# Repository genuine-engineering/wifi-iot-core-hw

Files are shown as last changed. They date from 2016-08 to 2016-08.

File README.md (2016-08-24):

# WIFI-IOT-CORE for IoT production project

_Wifi IoT Core_ project is to combine STM32 + ESP8266.

- ESP8266 is an amazing but cheap wifi chip. However it has many limitions, such as: no USB, limited analog interface, few I/O etc, while applications which are developed on it often need USB-Serial communication. Therefore many ESP8266-based modules in the world are added USB-TTL chip. While this brings some value to developing work, the value is just little in practical use. The design in this _Wifi IoT Core_ project uses the cheap STM32, with USB interface, to ease development, and complements many other features which are missing in ESP8266.

- The _Wifi IoT Core_ project including:

    + [wifi-iot-core-hw](https://github.com/genuine-engineering/wifi-iot-core-hw). Hardware is designed with [KiCad](http://kicad-pcb.org/)
    + [wifi-iot-core-stm32-fw](https://github.com/genuine-engineering/wifi-iot-core-stm32-fw). Firmware for STM32, based on [libopencm3](https://github.com/libopencm3/libopencm3)
    + [wifi-iot-core-esp8266-fw](https://github.com/genuine-engineering/wifi-iot-core-esp8266-fw). Firmware for ESP8266, based on [Espressif SDK 2.0](https://espressif.com/en/support/download/sdks-demos)

# Wifi-iot-core-hw
## Overview
The hardware is designed with [KiCad](http://kicad-pcb.org/) software. It includes two main components: ESP8266 and STM32F103C8T6.

 - STM32 has USB interface and is connected with ESP8266 via UART.

 - The output pins of the STM32 and ESP8266 are exposed for external use.

## Schematic

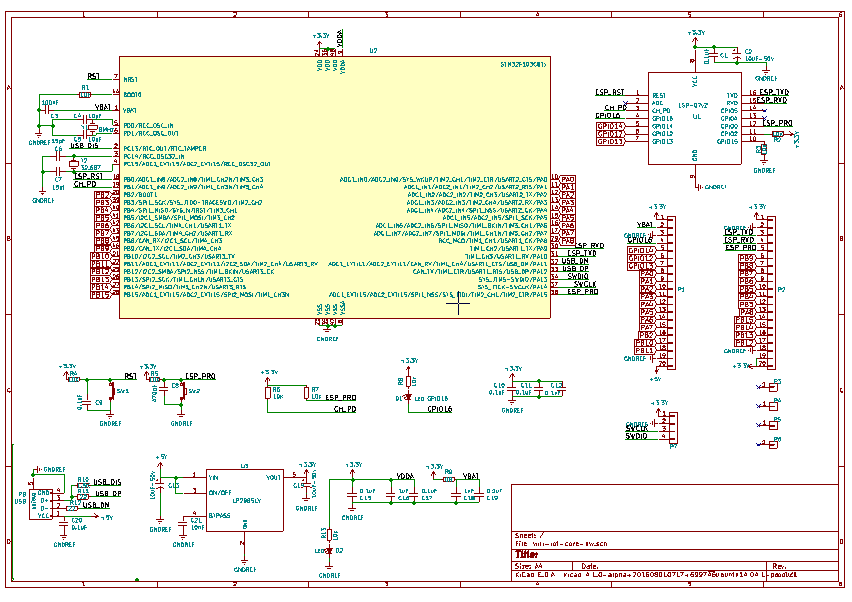
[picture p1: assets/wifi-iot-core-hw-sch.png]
Wifi IOT Core HW Schematic


## PCB

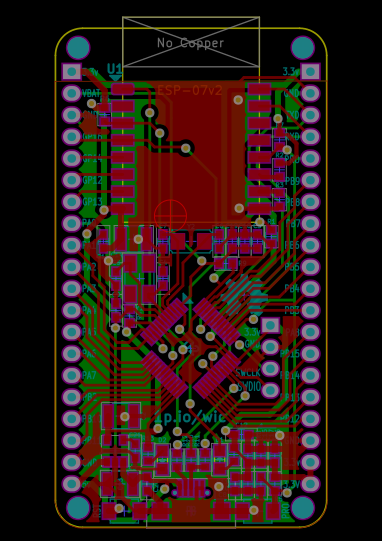
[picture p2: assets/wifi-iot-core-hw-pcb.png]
Wifi IOT Core HW PCB


## 3D

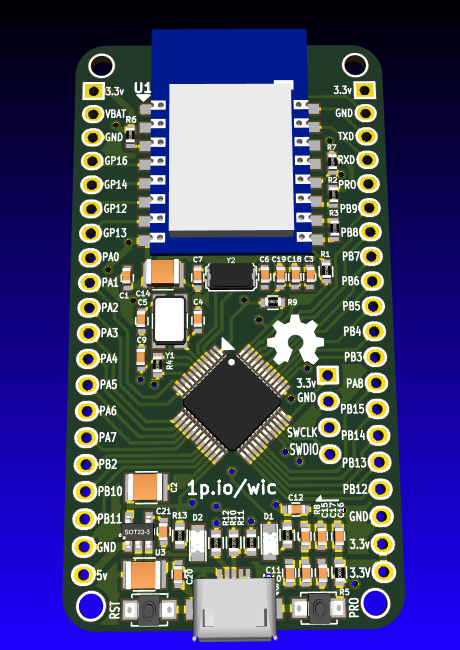
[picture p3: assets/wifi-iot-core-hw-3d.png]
Wifi IOT Core HW 3D


## BOM

| Refs | Value | Footprint |
|---|---|---|
| C7 | 15pf | lib:C_0603 |
| C1,C9-C12,C15,C17,C19,C20 | 0.1uF | lib:C_0603 |
| C4,C5 | 10pF | lib:C_0603 |
| C6 | 15pF | lib:C_0603 |
| C16,C18 | 1uF | lib:C_0603 |
| C3 | 100nF | lib:C_0603 |
| C21 | 10nF | lib:C_0603 |
| C2,C13,C14 | 10uF-50v | Capacitors_SMD:C_1210 |
| C8 | 470pF | lib:C_0603 |
| R11,R12 | 22 | lib:R_0603 |
| R10 | 1.5K | lib:R_0603 |
| R2-R5 | 10K | lib:R_0603 |
| R9 | 0R | lib:R_0603 |
| R1,R6-R8,R13 | 10k | lib:R_0603 |
| SW1 | RST | lib:SW_SPST_B3U-1000P-B |
| SW2 | SW_PUSH_SMALL_H | lib:SW_SPST_B3U-1000P-B |
| U1 | ESP-07v2 | lib:ESP-07v2-smd-16pin |
| U2 | STM32F103C8Tx | lib:LQFP-48_Pin1.7x0.3mm_Pitch0.5mm  |
| U3 | LP2985LV | TO_SOT_Packages_SMD:SOT-23-5 |
| P1,P2 | CONN_01X20 | Pin_Headers:Pin_Header_Straight_1x20 |
| P7 | CONN_01X04 | Pin_Headers:Pin_Header_Straight_1x04 |
| P3-P6 | CONN_01X01 | lib:MountingHole_2mm |
| P8 | USB | lib:Micro_usb_B_smd |
| Y2 | 32.687 | lib:crystal_smd_32.768_2Pin |
| Y1 | 8MHz | lib:Crystal_SMD_5032_4Pads |
| D2 | Led | LEDs:LED_0805 |
| D1 | Led GPIO16 | LEDs:LED_0805 |

## Gerber file

[Wifi IOT Core HW Gerber file](assets/gerber.zip)

## CC-BY license



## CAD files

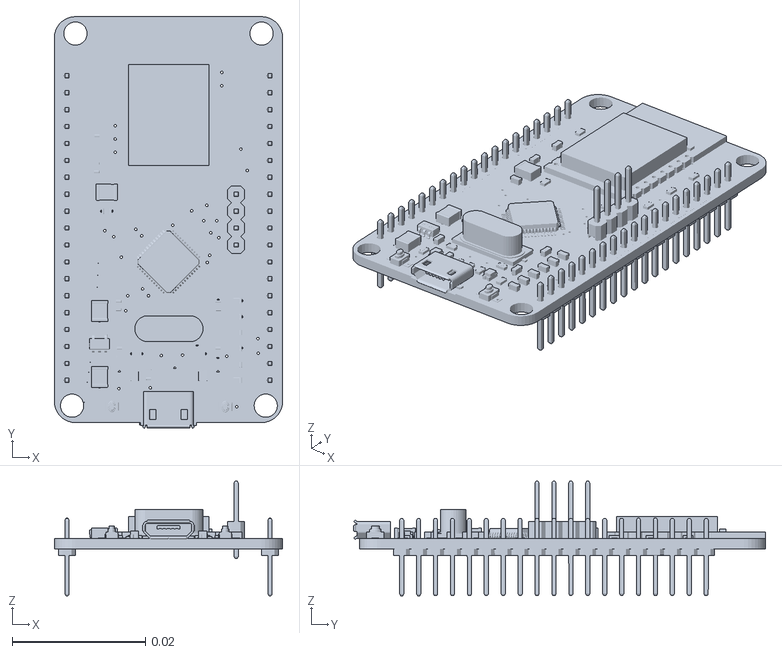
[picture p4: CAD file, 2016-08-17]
assets/wifi-iot-core-3d.wrl.stl
0.0343 x 0.0619 x 0.0172

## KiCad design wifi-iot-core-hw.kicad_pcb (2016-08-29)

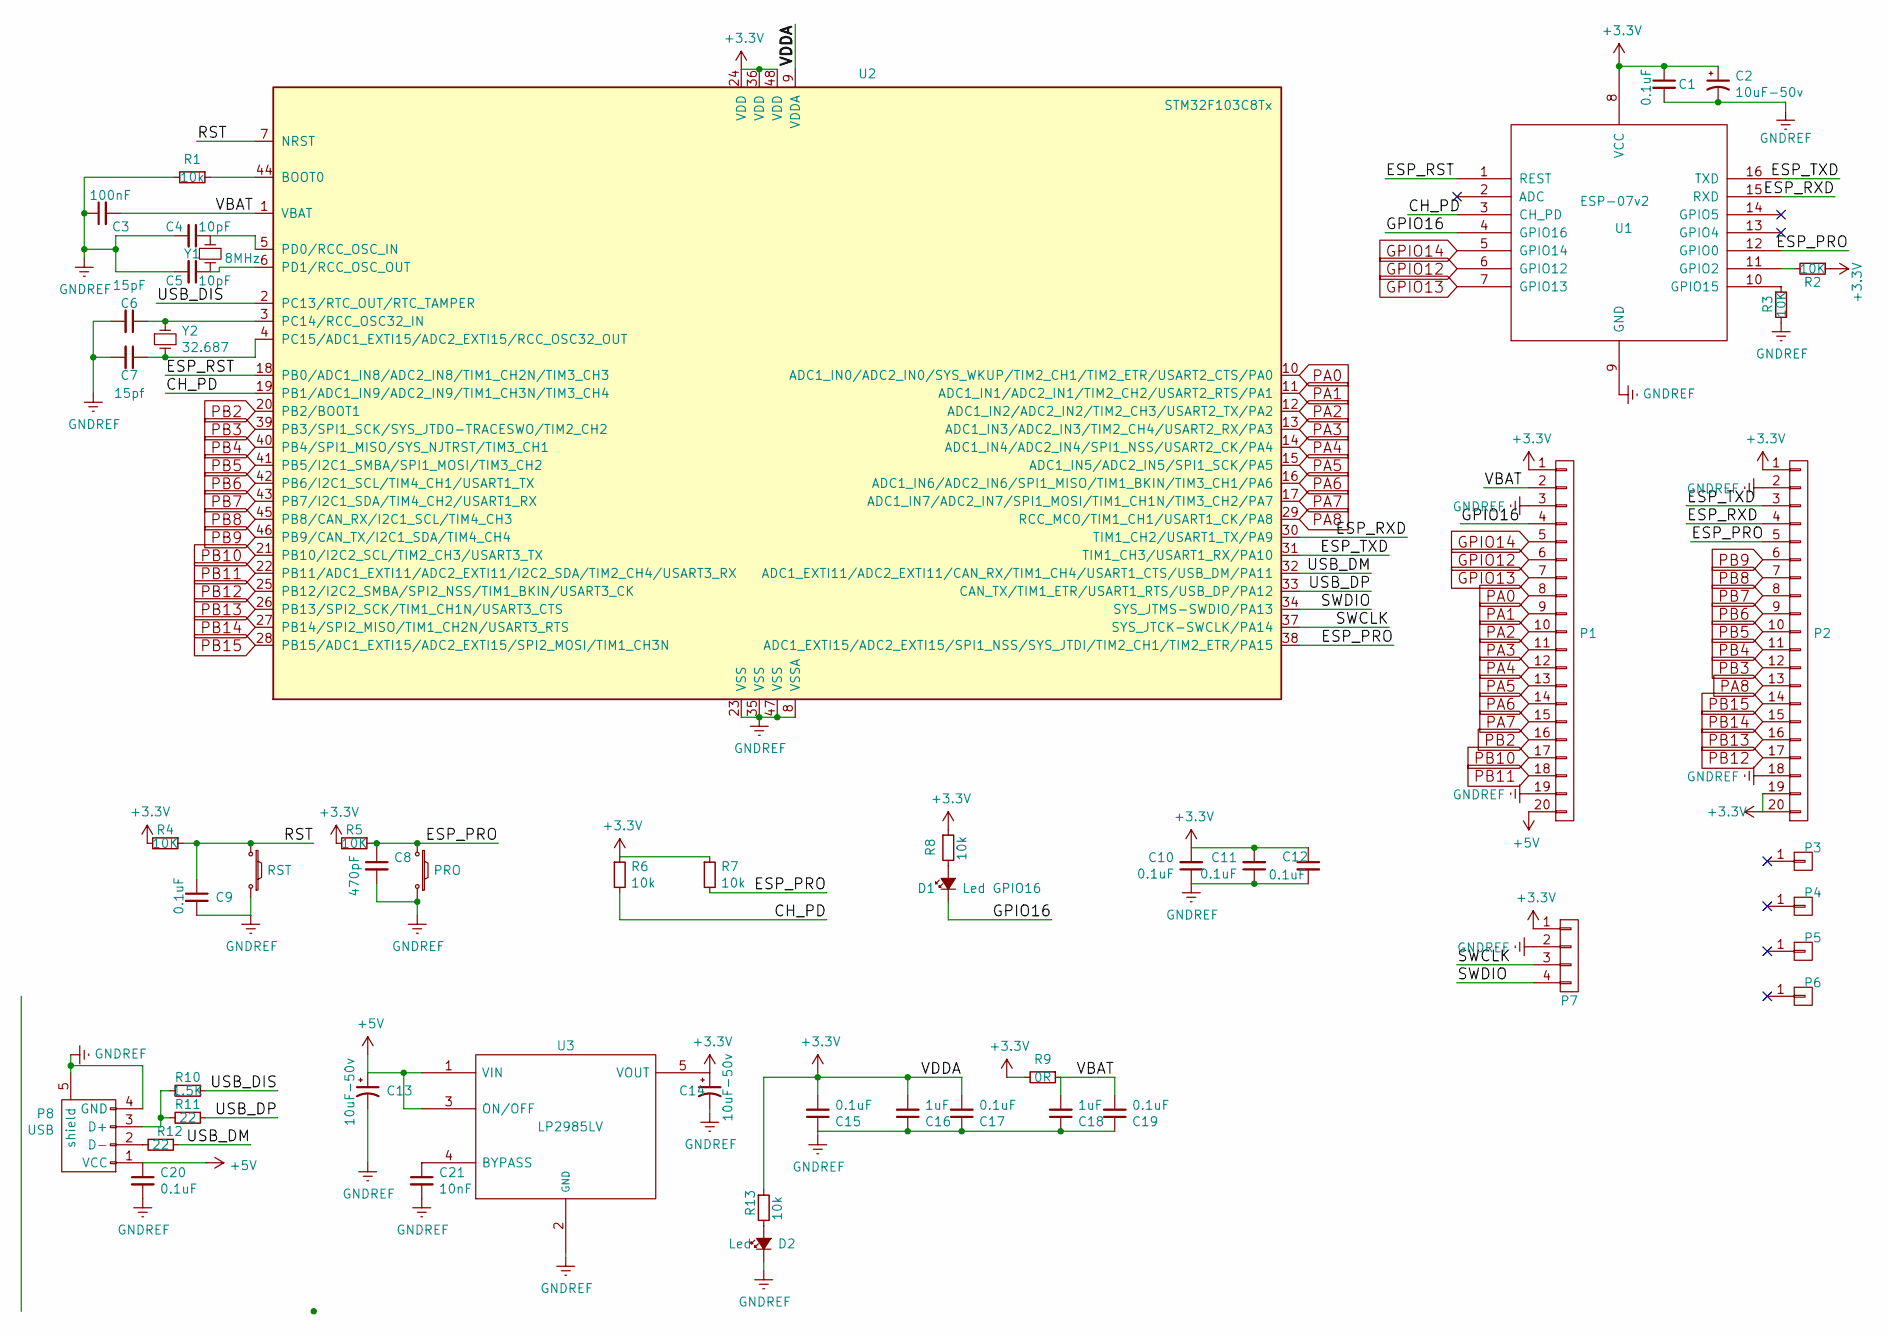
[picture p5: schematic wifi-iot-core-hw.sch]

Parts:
C1, C9, C10, C11, C12, C15, C17, C19, C20: 0.1uF; C_0603
C2, C13, C14: 10uF-50v; C_1210
C3: 100nF; C_0603
C4, C5: 10pF; C_0603
C6: 15pF; C_0603
C7: 15pf; C_0603
C8: 470pF; C_0603
C16, C18: 1uF; C_0603
C21: 10nF; C_0603
D1: Led GPIO16; LED_0805
D2: Led; LED_0805
P1, P2: CONN_01X20; Pin_Header_Straight_1x20
P3, P4, P5, P6: CONN_01X01; MountingHole_2mm
P7: CONN_01X04; Pin_Header_Straight_1x04
P8: USB; Micro_usb_B_smd
PRO: SW_PUSH_SMALL_H; SW_SPST_B3U-1000P-B
R1, R6, R7, R8, R13: 10k; R_0603
R2, R3, R4, R5: 10K; R_0603
R9: 0R; R_0603
R10: 1.5K; R_0603
R11, R12: 22; R_0603
RST: RST; SW_SPST_B3U-1000P-B
U1: ESP-07v2; ESP-07v2-smd-16pin
U2: STM32F103C8Tx; LQFP-48_Pin1.7x0.3mm_Pitch0.5mm
U3: LP2985LV; SOT-23-5
Y1: 8MHz; Crystal_SMD_5032_4Pads
Y2: 32.687; crystal_smd_32.768_2Pin

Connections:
+3V3: C1.1, C2.1, C10.2, C11.2, C12.1, C14.1, C15.2, C16.2, C17.2, P1.1, P2.1, P2.19, P2.20, P7.1, R2.1, R4.2, R5.2, R6.1, R7.1, R8.1, R9.2, R13.1, U1.8 (VCC), U2.9 (VDDA), U2.24 (VDD), U2.36 (VDD), U2.48 (VDD), U3.5 (VOUT)
+5V: C13.1, C20.1, P1.20, P8.1 (VCC), U3.1 (VIN), U3.3 (ON/OFF)
/CH_PD: R6.2, U1.3 (CH_PD), U2.19 (PB1/ADC1_IN9/ADC2_IN9/TIM1_CH3N/TIM3_CH4)
/ESP_PRO: C8.1, P2.5, PRO.1, R5.1, R7.2, U1.12 (GPIO0), U2.38 (ADC1_EXTI15/ADC2_EXTI15/SPI1_NSS/SYS_JT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)
/ESP_RST: U1.1 (REST), U2.18 (PB0/ADC1_IN8/ADC2_IN8/TIM1_CH2N/TIM3_CH3)
/ESP_RXD: P2.4, U1.15 (RXD), U2.30 (TIM1_CH2/USART1_TX/PA9)
/ESP_TXD: P2.3, U1.16 (TXD), U2.31 (TIM1_CH3/USART1_RX/PA10)
/GPIO16: D1.1 (K), P1.4, U1.4 (GPIO16)
/RST: C9.1, R4.1, RST.1, U2.7 (NRST)
/SWCLK: P7.3, U2.37 (SYS_JTCK-SWCLK/PA14)
/SWDIO: P7.4, U2.34 (SYS_JTMS-SWDIO/PA13)
/USB_DIS: R10.1, U2.2 (PC13/RTC_OUT/RTC_TAMPER)
/USB_DM: R12.1, U2.32 (ADC1_EXTI11/ADC2_EXTI11/CAN_RX/TIM1_CH4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)
/USB_DP: R11.1, U2.33 (CAN_TX/TIM1_ETR/USART1_RTS/USB_DP/PA12)
/VBAT: C3.2, C18.2, C19.2, P1.2, R9.1, U2.1 (VBAT)
GNDREF: C1.2, C2.2, C3.1, C4.2, C5.2, C6.2, C7.2, C8.2, C9.2, C10.1, C11.1, C12.2, C13.2, C14.2, C15.1, C16.1, C17.1, C18.1, C19.1, C20.2, C21.2, D2.1 (K), P1.3, P1.19, P2.2, P2.18, P7.2, P8.4 (GND), P8.5 (shield), PRO.2, R1.2, R3.2, RST.2, U1.9 (GND), U2.8 (VSSA), U2.23 (VSS), U2.35 (VSS), U2.47 (VSS), U3.2 (GND)
GPIO12: P1.6, U1.6 (GPIO12)
GPIO13: P1.7, U1.7 (GPIO13)
GPIO14: P1.5, U1.5 (GPIO14)
unnamed: C4.1, U2.5 (PD0/RCC_OSC_IN), Y1.1
unnamed: C5.1, U2.6 (PD1/RCC_OSC_OUT), Y1.2
unnamed: C6.1, U2.3 (PC14/RCC_OSC32_IN), Y2.1
unnamed: C7.1, U2.4 (PC15/ADC1_EXTI15/ADC2_EXTI15/RCC_OSC32_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), Y2.2
unnamed: C21.1, U3.4 (BYPASS)
unnamed: D1.2 (A), R8.2
unnamed: D2.2 (A), R13.2
unnamed: P8.2 (D-), R12.2
unnamed: P8.3 (D+), R10.2, R11.2
unnamed: R1.1, U2.44 (BOOT0)
unnamed: R2.2, U1.11 (GPIO2)
unnamed: R3.1, U1.10 (GPIO15)
PA0: P1.8, U2.10 (ADC1_IN0/ADC2_IN0/SYS_WKUP/TIM2_CH1/TIM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)
PA1: P1.9, U2.11 (ADC1_IN1/ADC2_IN1/TIM2_CH2/USART2_RTS/P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)
PA2: P1.10, U2.12 (ADC1_IN2/ADC2_IN2/TIM2_CH3/USART2_TX/PA2)
PA3: P1.11, U2.13 (ADC1_IN3/ADC2_IN3/TIM2_CH4/USART2_RX/PA3)
PA4: P1.12, U2.14 (ADC1_IN4/ADC2_IN4/SPI1_NSS/USART2_CK/PA4)
PA5: P1.13, U2.15 (ADC1_IN5/ADC2_IN5/SPI1_SCK/PA5)
PA6: P1.14, U2.16 (ADC1_IN6/ADC2_IN6/SPI1_MISO/TIM1_BKIN/T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)
PA7: P1.15, U2.17 (ADC1_IN7/ADC2_IN7/SPI1_MOSI/TIM1_CH1N/T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)
PA8: P2.13, U2.29 (RCC_MCO/TIM1_CH1/USART1_CK/PA8)
PB2: P1.16, U2.20 (PB2/BOOT1)
PB3: P2.12, U2.39 (PB3/SPI1_SCK/SYS_JTDO-TRACESWO/TIM2_CH2)
PB4: P2.11, U2.40 (PB4/SPI1_MISO/SYS_NJTRST/TIM3_CH1)
PB5: P2.10, U2.41 (PB5/I2C1_SMBA/SPI1_MOSI/TIM3_CH2)
PB6: P2.9, U2.42 (PB6/I2C1_SCL/TIM4_CH1/USART1_TX)
PB7: P2.8, U2.43 (PB7/I2C1_SDA/TIM4_CH2/USART1_RX)
PB8: P2.7, U2.45 (PB8/CAN_RX/I2C1_SCL/TIM4_CH3)
PB9: P2.6, U2.46 (PB9/CAN_TX/I2C1_SDA/TIM4_CH4)
PB10: P1.17, U2.21 (PB10/I2C2_SCL/TIM2_CH3/USART3_TX)
PB11: P1.18, U2.22 (PB11/ADC1_EXTI11/ADC2_EXTI11/I2C2_SDA/T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)
PB12: P2.17, U2.25 (PB12/I2C2_SMBA/SPI2_NSS/TIM1_BKIN/USART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)
PB13: P2.16, U2.26 (PB13/SPI2_SCK/TIM1_CH1N/USART3_CTS)
PB14: P2.15, U2.27 (PB14/SPI2_MISO/TIM1_CH2N/USART3_RTS)
PB15: P2.14, U2.28 (PB15/ADC1_EXTI15/ADC2_EXTI15/SPI2_MOSI/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)

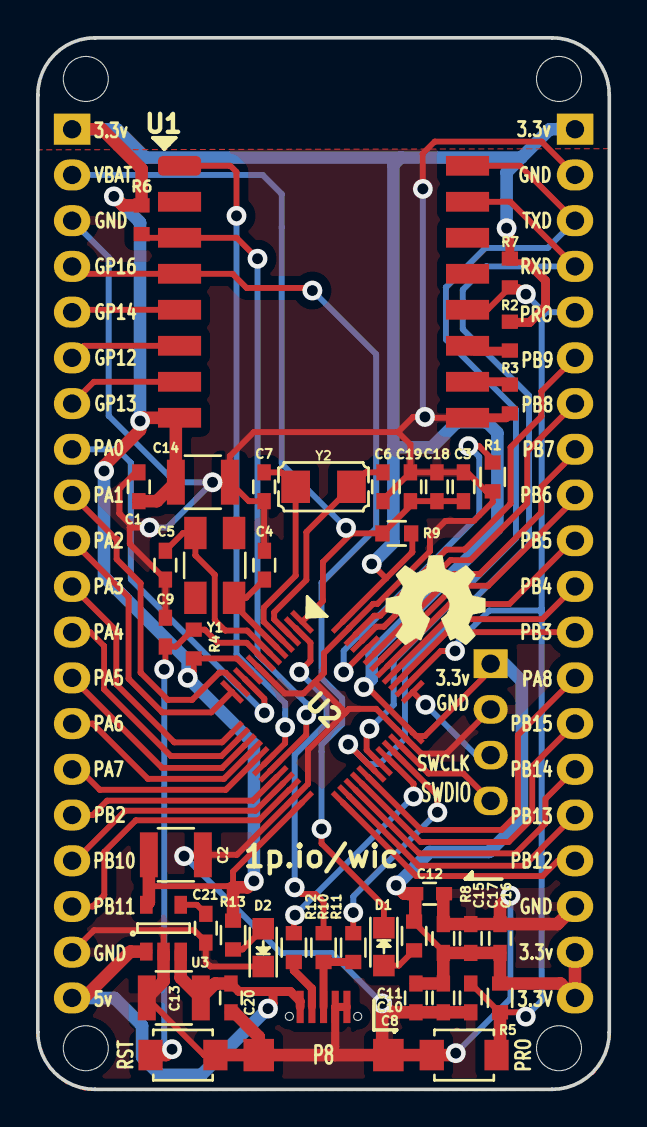
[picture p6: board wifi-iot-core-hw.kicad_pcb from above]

Board: 2 copper layers, 31.8 x 58.4 mm, 52 parts (0 on the bottom side), 54 nets.

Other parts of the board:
VAL**: oshw_logo_500; logo5

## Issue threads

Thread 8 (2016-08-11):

PCB Error on KiCad 4.0.3, Ubuntu 16.04.1

cuong0993, 2016-08-11:
Hi all,
I got this eror on KiCad 4.0.3, Ubuntu 16.04.1:

```
Error loading board.
PARSE_ERROR: Expecting 'circle, rectangle, oval, or trapezoid' in input/source
'/media/cuong/130C70700F0058F8/iot-core-hw-master/iot-core.kicad_pcb'
line 1794
offset 16
from /build/kicad-erO_vy/kicad-4.0.3+e1/kicad/common/dsnlexer.cpp : Expecting() : line 369
```

How can I fix it?

tuanpmt, 2016-08-11:
i don't know exactly what happen, but may you try re-install  Kicad nighty build.
We're using nighty build for now

```
sudo add-apt-repository --yes ppa:js-reynaud/ppa-kicad
sudo apt-get update
sudo apt-get install kicad
```

cuong0993, 2016-08-12:
Thank you. It work now.

Closed 2016-08-12.

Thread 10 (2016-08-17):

First fabrication pcb feedback

tuanpmt, 2016-08-17:
- Copper Pour override RF antenna
- PCB can be reduce size
- change crystal to smaller
- Modify PAD of resistor/cap/usb bigger

Some helps for first time resolve problem by commit
https://help.github.com/articles/closing-issues-via-commit-messages/

Closed 2016-08-19.

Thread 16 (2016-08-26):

Project Definition and Goals

mariobehling, 2016-08-26:
Very interesting! Could you help me to understand this better.

wifi-iot-core-hw. Hardware is designed with KiCad
* What is the goal of the hardware? What are the use cases?

wifi-iot-core-stm32-fw. Firmware for STM32, based on libopencm3
* What are the changes to libopencm3?

wifi-iot-core-esp8266-fw. Firmware for ESP8266, based on Espressif SDK 2.0
* What is the differences to the Esspressif firmware?

tuanpmt, 2016-08-26:
Hi Mario,
Thank you for your interest
The main project is iot-core, wifi-iot-core is just one part of it. Include:
- wifi-iot-core
- gsm-iot-core
- lora-iot-core
- ble-iot-core

I want to develop this hardware platform for any individual or organization to apply it to mass production, the cost of transforming from prototype to production is smallest. These designs were selected as the common design and standards for IoT applications.
- Project with suffix `hw` mean: hardware design file, it is the basic design and easy to add other features. Can be likened boilerplate project.
- Project with suffix `fw` mean: firmware project, It will be added to the function must be included in the project: usb stack, wps, smartconfig ... and templates for applications.
- Some of boilerplate application such as: mqtt, rest, websocket, aws iot, fota ... to easy start new project.

About wifi-iot-core:
`wifi-iot-core-hw`: What is the goal of the hardware? What are the use cases? (from README)

> ESP8266 is an amazing but cheap wifi chip. However it has many limitions, such as: no USB, limited analog interface, few I/O etc, while applications which are developed on it often need USB-Serial communication. Therefore many ESP8266-based modules in the world are added USB-TTL chip. While this brings some value to developing work, the value is just little in practical use. The design in this Wifi IoT Core project uses the cheap STM32, with USB interface, to ease development, and complements many other features which are missing in ESP8266.

`wifi-iot-core-stm32-fw` What are the changes to libopencm3?

> It is based libopencm3 such as HAL library and implementing functions such as usb-cdc basic, adc ... SLIP to server command for ESP8266

`wifi-iot-core-esp8266-fw` What is the differences to the Esspressif firmware?

> It is based Espressif NONOS SDK 2.0, which ability to control STM32 and realize the features necessary for the IoT application: FOTA, smartconfig, file system ...

Frankly, this project is like a combination of boilerplate projects prepared for the IoT  production 😄

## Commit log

2016-08-05 Update HW
    [nchp-iot-core.kicad_pcb, nchp-iot-core.sch]
2016-08-06 Confirm PIN 1 of ESP8266 & STM32
    [nchp-iot-core.kicad_pcb]
2016-08-06 Fix name headers
    [nchp-iot-core.kicad_pcb]
2016-08-08 Update README file, name pin headers, pin 1 STM32 & ESP8266
    [nchp-iot-core.kicad_pcb]
2016-08-08 ADD gerber file
2016-08-09 Modified README file, rename project, add gerber file, anh 3d. ADD lib ESP8266 & BUTTON
    [iot-core.kicad_pcb, iot-core.sch]
2016-08-09 Fix link lib 3D file
    [iot-core.kicad_pcb]
2016-08-10 Fix DAO DONG THACH ANH KHONG NOI GND, pin ESP_PRO to PB0, GPIO16 to PB11,DELETE header BOOT 0
    [iot-core.kicad_pcb, iot-core.sch]
2016-08-10 Add sub Englishon README file
    [iot-core.sch]
2016-08-16 Fix name project
    [wifi-iot-core-3d.wrl.stl, wifi-iot-core-hw.kicad_pcb, wifi-iot-core-hw.sch]
2016-08-19 Fix Schematic & PCB
    [wifi-iot-core-hw.kicad_pcb, wifi-iot-core-hw.sch]
2016-08-19 resolve #10
    [wifi-iot-core-hw.kicad_pcb]
2016-08-26 Drop pin GPIO16 at pin STM32, add address support in PCB & size PCB 2,3x1,25 inch (5,8x3,2 mm)
    [wifi-iot-core-hw.kicad_pcb, wifi-iot-core-hw.sch]
2016-08-26 Fix assets file
    [wifi-iot-core-hw.kicad_pcb, wifi-iot-core-hw.sch]
